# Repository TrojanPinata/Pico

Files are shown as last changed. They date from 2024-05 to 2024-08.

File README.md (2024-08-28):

# Pico
This project is a precursor to a future project which I aim to use a RP2040 as the microcontroller as the core of a keyboard, very similar to my original keyboard but with PCBA.

The goal of this was to prove the feasability of using PCBA as well as prove my ability to make a functioning RP2040 microcontroller board. The Pi Pico was simply chosen as it was a very accessible option.

If you want to use this project, it should be noted that this is open source, but I would rather you simply use this as a reference. Putting that much confidence in someone elses work is dangerous, and I cannot guarantee spec with the original.

The only major changes with these boards vs the real deal are the addition of a reset button and usb-c header (something that should be on the original :| )



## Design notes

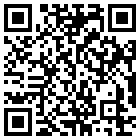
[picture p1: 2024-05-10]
assets/qr1.gif

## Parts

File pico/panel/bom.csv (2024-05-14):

Designator | Footprint | Quantity | Value | LCSC Part #
C1_6, C1_5, C1_4, C1_3, C1_2, C1, C10_6, C10_5, C10_4, C10_3, C10_2, C10, C16_6, C16_5, C16_4, C16_3, C16_2, C16, C17_6, C17_5, C17_4, C17_3, C17_2, C17, C2_6, C2_5, C2_4, C2_3, C2_2, C2, C4_6, C4_5, C4_4, C4_3, C4_2, C4, C5_6, C5_5, C5_4, C5_3, C5_2, C5, C6_6, C6_5, C6_4, C6_3, C6_2, C6, C7_6, C7_5, C7_4, C7_3, C7_2, C7, C8_6, C8_5, C8_4, C8_3, C8_2, C8, C9_6, C9_5, C9_4, C9_3, C9_2, C9 | 0402 | 66 | 0.1uF | C1525
C11_6, C11_5, C11_4, C11_3, C11_2, C11, C12_6, C12_5, C12_4, C12_3, C12_2, C12 | 0402 | 12 | 2.2uF | C12530
C13_6, C13_5, C13_4, C13_3, C13_2, C13, C19_6, C19_5, C19_4, C19_3, C19_2, C19 | 0402 | 12 | 10uF | C15525
C14_6, C14_5, C14_4, C14_3, C14_2, C14, C15_6, C15_5, C15_4, C15_3, C15_2, C15 | 0402 | 12 | 20pF | C1554
C3_6, C3_5, C3_4, C3_3, C3_2, C3 | 0402 | 6 | 1uF | C52923
D1_6, D1_5, D1_4, D1_3, D1_2, D1 | 0402 | 6 | LED | C2856703
D3_6, D3_5, D3_4, D3_3, D3_2, D3 | D_SOD-123 | 6 | 1N4002W | C169542
F1_6, F1_5, F1_4, F1_3, F1_2, F1 | 0805 | 6 | 0805L050WR | C207022
FB1_6, FB1_5, FB1_4, FB1_3, FB1_2, FB1 | 0402 | 6 | FB | C160973
J4_6, J4_5, J4_4, J4_3, J4_2, J4 | HRO-TYPE-C-31-M-12 | 6 | USB_C_Receptacle_USB2.0 | C165948
R1_6, R1_5, R1_4, R1_3, R1_2, R1, R2_6, R2_5, R2_4, R2_3, R2_2, R2 | 0402 | 12 | 27 | C25100
R10_6, R10_5, R10_4, R10_3, R10_2, R10, R14_6, R14_5, R14_4, R14_3, R14_2, R14, R9_6, R9_5, R9_4, R9_3, R9_2, R9 | 0402 | 18 | 10k | C25744
R11_6, R11_5, R11_4, R11_3, R11_2, R11, R12_6, R12_5, R12_4, R12_3, R12_2, R12 | 0402 | 12 | 5.1k | C25905
R13_6, R13_5, R13_4, R13_3, R13_2, R13 | 0402 | 6 | 5.6k | C25908
R15_6, R15_5, R15_4, R15_3, R15_2, R15 | 0402 | 6 | 100k | C25741
R3_6, R3_5, R3_4, R3_3, R3_2, R3 | 0402 | 6 | 200 | C25087
R4_6, R4_5, R4_4, R4_3, R4_2, R4 | 0402 | 6 | 1 | C25086
R5_6, R5_5, R5_4, R5_3, R5_2, R5 | 0402 | 6 | 470 | C25117
R7_6, R7_5, R7_4, R7_3, R7_2, R7, R8_6, R8_5, R8_4, R8_3, R8_2, R8 | 0402 | 12 | 1k | C11702
SW1_6, SW1_5, SW1_4, SW1_3, SW1_2, SW1 | SW_Push_SPST_NO_Alps_SKRK | 6 | RESET | C139797
SW2_6, SW2_5, SW2_4, SW2_3, SW2_2, SW2 | SW_Push_SPST_NO_Alps_SKRK | 6 | BOOT_SEL | C139797
U1_6, U1_5, U1_4, U1_3, U1_2, U1 | RP2040-QFN-56 | 6 | RP2040 | C2040
U2_6, U2_5, U2_4, U2_3, U2_2, U2 | SON-8-1EP_3x2mm_P0.5mm_EP1.4x1.6mm | 6 | W25Q16JVUXIQ | C2843335
U3_6, U3_5, U3_4, U3_3, U3_2, U3 | SOT-23-5 | 6 | TLV75533PDBVR | C404027
Y1_6, Y1_5, Y1_4, Y1_3, Y1_2, Y1 | Crystal_SMD_3225-4Pin_3.2x2.5mm | 6 | 12MHz | C9002

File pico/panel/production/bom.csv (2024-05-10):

Designator | Footprint | Quantity | Value | LCSC Part #
C1_6, C1_5, C1_4, C1_3, C1_2, C1, C10_6, C10_5, C10_4, C10_3, C10_2, C10, C16_6, C16_5, C16_4, C16_3, C16_2, C16, C17_6, C17_5, C17_4, C17_3, C17_2, C17, C2_6, C2_5, C2_4, C2_3, C2_2, C2, C4_6, C4_5, C4_4, C4_3, C4_2, C4, C5_6, C5_5, C5_4, C5_3, C5_2, C5, C6_6, C6_5, C6_4, C6_3, C6_2, C6, C7_6, C7_5, C7_4, C7_3, C7_2, C7, C8_6, C8_5, C8_4, C8_3, C8_2, C8, C9_6, C9_5, C9_4, C9_3, C9_2, C9 | 0402 | 66 | 0.1uF
C11_6, C11_5, C11_4, C11_3, C11_2, C11, C12_6, C12_5, C12_4, C12_3, C12_2, C12 | 0402 | 12 | 2.2uF
C13_6, C13_5, C13_4, C13_3, C13_2, C13, C19_6, C19_5, C19_4, C19_3, C19_2, C19 | 0402 | 12 | 10uF
C14_6, C14_5, C14_4, C14_3, C14_2, C14, C15_6, C15_5, C15_4, C15_3, C15_2, C15 | 0402 | 12 | 22pF
C3_6, C3_5, C3_4, C3_3, C3_2, C3 | 0402 | 6 | 1uF
D1_6, D1_5, D1_4, D1_3, D1_2, D1 | 0402 | 6 | LED
D3_6, D3_5, D3_4, D3_3, D3_2, D3 | D_SOD-123 | 6 | 1N4002W
F1_6, F1_5, F1_4, F1_3, F1_2, F1 | 0805 | 6 | 0805L050WR
FB1_6, FB1_5, FB1_4, FB1_3, FB1_2, FB1 | 0402 | 6 | FB
J1_6, J1_5, J1_4, J1_3, J1_2, J1 | PinHeader_1x20_P2.54mm_Vertical | 6 | LEFT_PINS
J2_6, J2_5, J2_4, J2_3, J2_2, J2 | PinHeader_1x20_P2.54mm_Vertical | 6 | RIGHT_PINS
J3_6, J3_5, J3_4, J3_3, J3_2, J3 | PinHeader_1x03_P2.54mm_Vertical | 6 | BOTTOM_PINS
J4_6, J4_5, J4_4, J4_3, J4_2, J4 | HRO-TYPE-C-31-M-12 | 6 | USB_C_Receptacle_USB2.0
KiKit_MB_10_1, KiKit_MB_10_2, KiKit_MB_10_3, KiKit_MB_10_4, KiKit_MB_10_5, KiKit_MB_10_6, KiKit_MB_10_7, KiKit_MB_10_8, KiKit_MB_11_1, KiKit_MB_11_2, KiKit_MB_11_3, KiKit_MB_11_4, KiKit_MB_11_5, KiKit_MB_11_6, KiKit_MB_11_7, KiKit_MB_11_8, KiKit_MB_12_1, KiKit_MB_12_2, KiKit_MB_12_3, KiKit_MB_12_4, KiKit_MB_12_5, KiKit_MB_12_6, KiKit_MB_12_7, KiKit_MB_12_8, KiKit_MB_13_1, KiKit_MB_13_2, KiKit_MB_13_3, KiKit_MB_13_4, KiKit_MB_13_5, KiKit_MB_13_6, KiKit_MB_13_7, KiKit_MB_13_8, KiKit_MB_14_1, KiKit_MB_14_2, KiKit_MB_14_3, KiKit_MB_14_4, KiKit_MB_14_5, KiKit_MB_14_6, KiKit_MB_14_7, KiKit_MB_14_8, KiKit_MB_15_1, KiKit_MB_15_2, KiKit_MB_15_3, KiKit_MB_15_4, KiKit_MB_15_5, KiKit_MB_15_6, KiKit_MB_15_7, KiKit_MB_15_8, KiKit_MB_16_1, KiKit_MB_16_2, KiKit_MB_16_3, KiKit_MB_16_4, KiKit_MB_16_5, KiKit_MB_16_6, KiKit_MB_16_7, KiKit_MB_16_8, KiKit_MB_17_1, KiKit_MB_17_2, KiKit_MB_17_3, KiKit_MB_17_4, KiKit_MB_17_5, KiKit_MB_17_6, KiKit_MB_17_7, KiKit_MB_17_8, KiKit_MB_18_1, KiKit_MB_18_2, KiKit_MB_18_3, KiKit_MB_18_4, KiKit_MB_18_5, KiKit_MB_18_6, KiKit_MB_18_7, KiKit_MB_18_8, KiKit_MB_19_1, KiKit_MB_19_2, KiKit_MB_19_3, KiKit_MB_19_4, KiKit_MB_19_5, KiKit_MB_19_6, KiKit_MB_19_7, KiKit_MB_19_8, KiKit_MB_1_1, KiKit_MB_1_2, KiKit_MB_1_3, KiKit_MB_1_4, KiKit_MB_1_5, KiKit_MB_1_6, KiKit_MB_1_7, KiKit_MB_1_8, KiKit_MB_20_1, KiKit_MB_20_2, KiKit_MB_20_3, KiKit_MB_20_4, KiKit_MB_20_5, KiKit_MB_20_6, KiKit_MB_20_7, KiKit_MB_20_8, KiKit_MB_21_1, KiKit_MB_21_2, KiKit_MB_21_3, KiKit_MB_21_4, KiKit_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 | NPTH | 200 | NPTH
KiKit_MB_33_1, KiKit_MB_33_2, KiKit_MB_33_3, KiKit_MB_33_4, KiKit_MB_33_5, KiKit_MB_33_6, KiKit_MB_33_7, KiKit_MB_33_8, KiKit_MB_34_1, KiKit_MB_34_2, KiKit_MB_34_3, KiKit_MB_34_4, KiKit_MB_34_5, KiKit_MB_34_6, KiKit_MB_34_7, KiKit_MB_34_8, KiKit_MB_35_1, KiKit_MB_35_2, KiKit_MB_35_3, KiKit_MB_35_4, KiKit_MB_35_5, KiKit_MB_35_6, KiKit_MB_35_7, KiKit_MB_35_8, KiKit_MB_36_1, KiKit_MB_36_2, KiKit_MB_36_3, KiKit_MB_36_4, KiKit_MB_36_5, KiKit_MB_36_6, KiKit_MB_36_7, KiKit_MB_36_8, KiKit_MB_37_1, KiKit_MB_37_2, KiKit_MB_37_3, KiKit_MB_37_4, KiKit_MB_37_5, KiKit_MB_37_6, KiKit_MB_37_7, KiKit_MB_37_8, KiKit_MB_38_1, KiKit_MB_38_2, KiKit_MB_38_3, KiKit_MB_38_4, KiKit_MB_38_5, KiKit_MB_38_6, KiKit_MB_38_7, KiKit_MB_38_8, KiKit_MB_39_1, KiKit_MB_39_2, KiKit_MB_39_3, KiKit_MB_39_4, KiKit_MB_39_5, KiKit_MB_39_6, KiKit_MB_39_7, KiKit_MB_39_8, KiKit_MB_3_1, KiKit_MB_3_2, KiKit_MB_3_3, KiKit_MB_3_4, KiKit_MB_3_5, KiKit_MB_3_6, KiKit_MB_3_7, KiKit_MB_3_8, KiKit_MB_40_1, KiKit_MB_40_2, KiKit_MB_40_3, KiKit_MB_40_4, KiKit_MB_40_5, KiKit_MB_40_6, KiKit_MB_40_7, KiKit_MB_40_8, KiKit_MB_41_1, KiKit_MB_41_2, KiKit_MB_41_3, KiKit_MB_41_4, KiKit_MB_41_5, KiKit_MB_41_6, KiKit_MB_41_7, KiKit_MB_41_8, KiKit_MB_42_1, KiKit_MB_42_2, KiKit_MB_42_3, KiKit_MB_42_4, KiKit_MB_42_5, KiKit_MB_42_6, KiKit_MB_42_7, KiKit_MB_42_8, KiKit_MB_43_1, KiKit_MB_43_2, KiKit_MB_43_3, KiKit_MB_43_4, KiKit_MB_43_5, KiKit_MB_43_6, KiKit_MB_43_7, KiKit_MB_43_8, KiKit_MB_44_1, KiKit_MB_44_2, KiKit_MB_44_3, KiKit_MB_44_4, KiKit_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 | NPTH | 200 | NPTH
KiKit_MB_57_5, KiKit_MB_57_6, KiKit_MB_57_7, KiKit_MB_58_1, KiKit_MB_58_2, KiKit_MB_58_3, KiKit_MB_58_4, KiKit_MB_58_5, KiKit_MB_58_6, KiKit_MB_58_7, KiKit_MB_59_1, KiKit_MB_59_2, KiKit_MB_59_3, KiKit_MB_59_4, KiKit_MB_59_5, KiKit_MB_59_6, KiKit_MB_59_7, KiKit_MB_5_1, KiKit_MB_5_2, KiKit_MB_5_3, KiKit_MB_5_4, KiKit_MB_5_5, KiKit_MB_5_6, KiKit_MB_5_7, KiKit_MB_5_8, KiKit_MB_60_1, KiKit_MB_60_2, KiKit_MB_60_3, KiKit_MB_60_4, KiKit_MB_60_5, KiKit_MB_60_6, KiKit_MB_60_7, KiKit_MB_6_1, KiKit_MB_6_2, KiKit_MB_6_3, KiKit_MB_6_4, KiKit_MB_6_5, KiKit_MB_6_6, KiKit_MB_6_7, KiKit_MB_6_8, KiKit_MB_7_1, KiKit_MB_7_2, KiKit_MB_7_3, KiKit_MB_7_4, KiKit_MB_7_5, KiKit_MB_7_6, KiKit_MB_7_7, KiKit_MB_7_8, KiKit_MB_8_1, KiKit_MB_8_2, KiKit_MB_8_3, KiKit_MB_8_4, KiKit_MB_8_5, KiKit_MB_8_6, KiKit_MB_8_7, KiKit_MB_8_8, KiKit_MB_9_1, KiKit_MB_9_2, KiKit_MB_9_3, KiKit_MB_9_4, KiKit_MB_9_5, KiKit_MB_9_6, KiKit_MB_9_7, KiKit_MB_9_8 | NPTH | 64 | NPTH
R1_6, R1_5, R1_4, R1_3, R1_2, R1, R2_6, R2_5, R2_4, R2_3, R2_2, R2 | 0402 | 12 | 27
R10_6, R10_5, R10_4, R10_3, R10_2, R10, R14_6, R14_5, R14_4, R14_3, R14_2, R14, R9_6, R9_5, R9_4, R9_3, R9_2, R9 | 0402 | 18 | 10k
R11_6, R11_5, R11_4, R11_3, R11_2, R11, R12_6, R12_5, R12_4, R12_3, R12_2, R12 | 0402 | 12 | 5.1k
R13_6, R13_5, R13_4, R13_3, R13_2, R13 | 0402 | 6 | 5.6k
R15_6, R15_5, R15_4, R15_3, R15_2, R15 | 0402 | 6 | 100k
R3_6, R3_5, R3_4, R3_3, R3_2, R3 | 0402 | 6 | 200
R4_6, R4_5, R4_4, R4_3, R4_2, R4 | 0402 | 6 | 1
R5_6, R5_5, R5_4, R5_3, R5_2, R5 | 0402 | 6 | 470
R7_6, R7_5, R7_4, R7_3, R7_2, R7, R8_6, R8_5, R8_4, R8_3, R8_2, R8 | 0402 | 12 | 1k
SW1_6, SW1_5, SW1_4, SW1_3, SW1_2, SW1 | SW_Push_SPST_NO_Alps_SKRK | 6 | RESET
SW2_6, SW2_5, SW2_4, SW2_3, SW2_2, SW2 | SW_Push_SPST_NO_Alps_SKRK | 6 | BOOT_SEL
TP1_6, TP1_5, TP1_4, TP1_3, TP1_2, TP1, TP2_6, TP2_5, TP2_4, TP2_3, TP2_2, TP2, TP3_6, TP3_5, TP3_4, TP3_3, TP3_2, TP3 | CustomTestPoint | 18 | TestPoint
U1_6, U1_5, U1_4, U1_3, U1_2, U1 | RP2040-QFN-56 | 6 | RP2040
U2_6, U2_5, U2_4, U2_3, U2_2, U2 | SON-8-1EP_3x2mm_P0.5mm_EP1.4x1.6mm | 6 | W25Q16JVUXIQ
U3_6, U3_5, U3_4, U3_3, U3_2, U3 | SOT-23-5 | 6 | TLV75533PDBVR
Y1_6, Y1_5, Y1_4, Y1_3, Y1_2, Y1 | Crystal_SMD_3225-4Pin_3.2x2.5mm | 6 | 12MHz

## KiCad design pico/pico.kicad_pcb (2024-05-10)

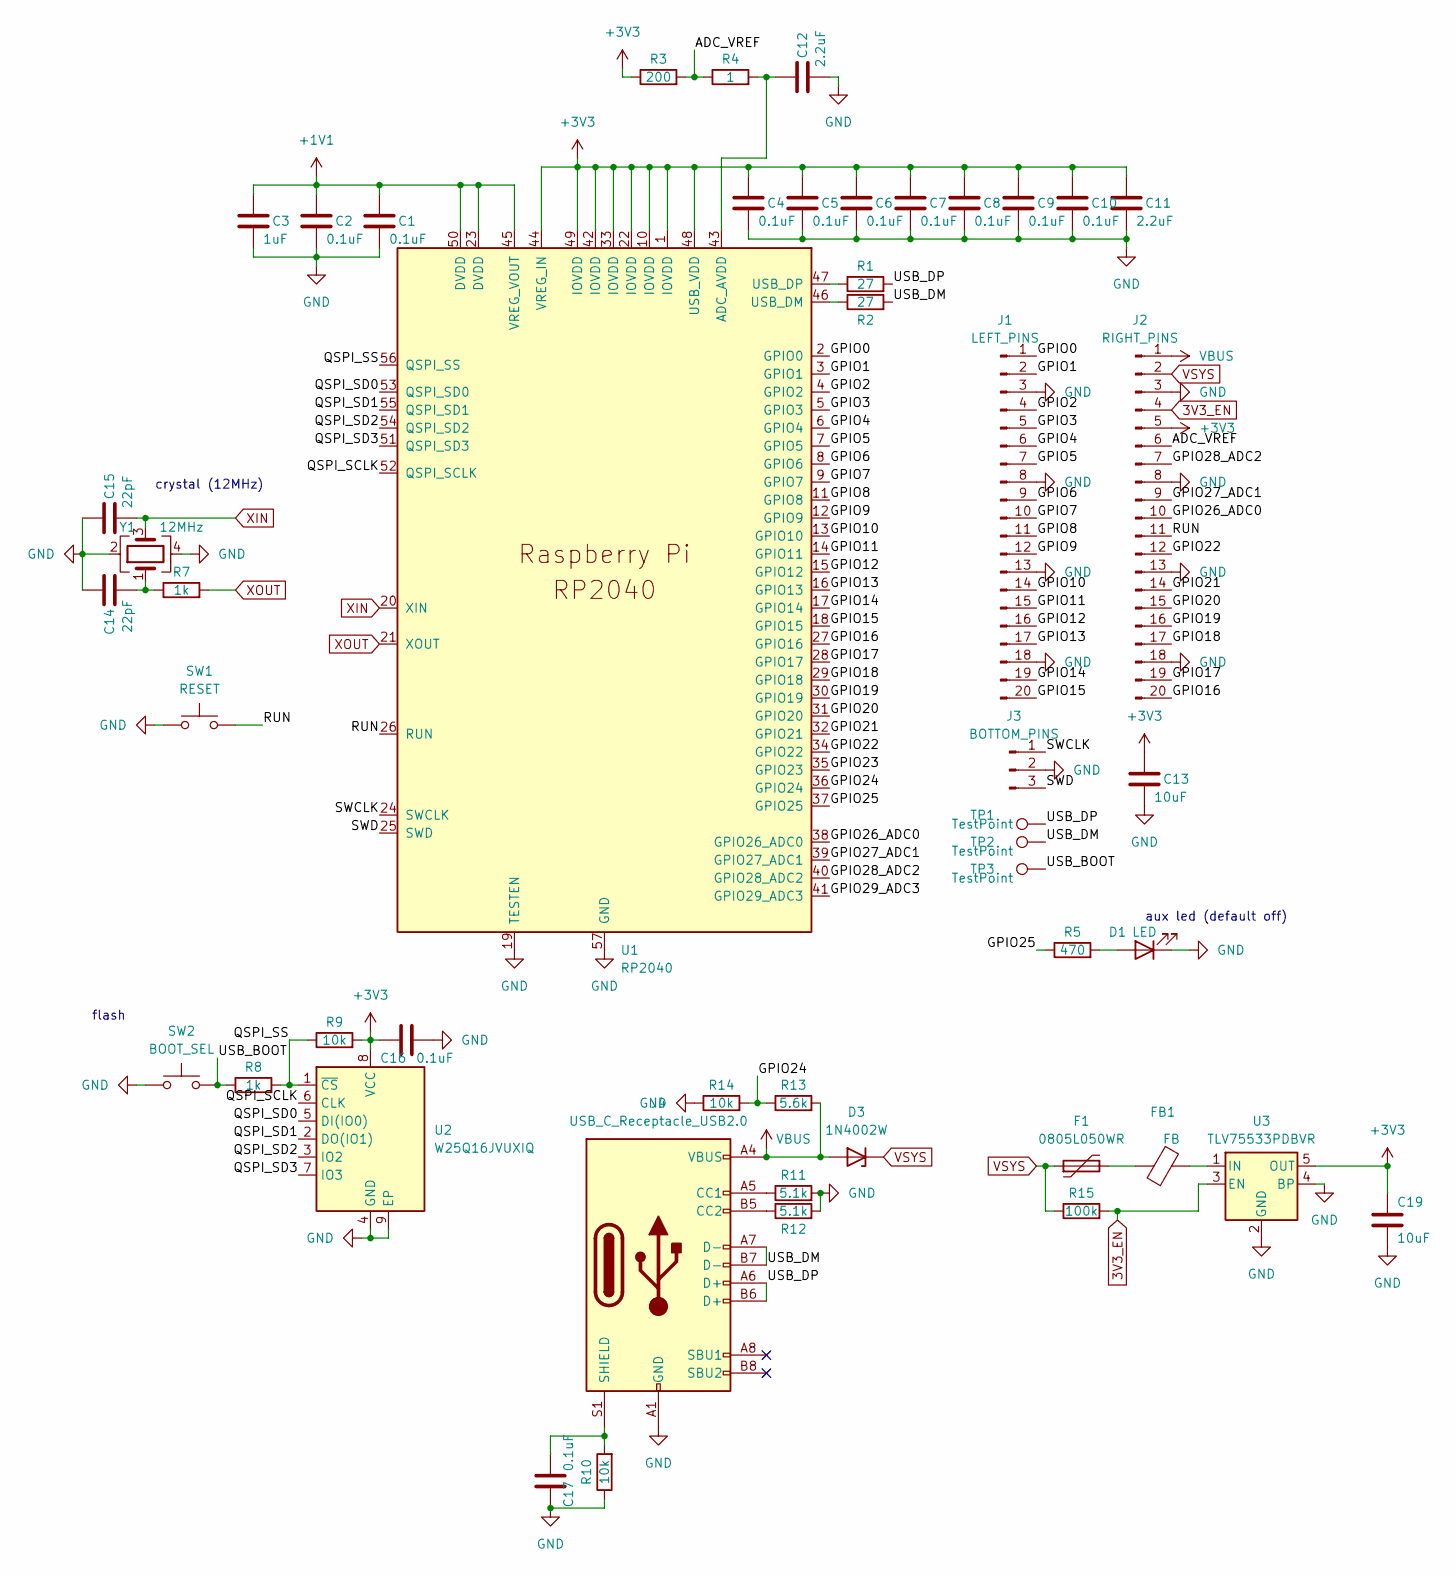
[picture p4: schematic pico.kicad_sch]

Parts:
C1, C2, C4, C5, C6, C7, C8, C9, C10, C16, C17: 0.1uF; C_0402_1005Metric
C3: 1uF; C_0402_1005Metric
C11, C12: 2.2uF; C_0402_1005Metric
C13, C19: 10uF; C_0402_1005Metric
C14, C15: 22pF; C_0402_1005Metric
D1: LED; LED_0402_1005Metric
D3: 1N4002W; D_SOD-123
F1: 0805L050WR; Fuse_0805_2012Metric
FB1: FB; R_0402_1005Metric
J1: LEFT_PINS; PinHeader_1x20_P2.54mm_Vertical
J2: RIGHT_PINS; PinHeader_1x20_P2.54mm_Vertical
J3: BOTTOM_PINS; PinHeader_1x03_P2.54mm_Vertical
J4: USB_C_Receptacle_USB2.0; HRO-TYPE-C-31-M-12
R1, R2: 27; R_0402_1005Metric
R3: 200; R_0402_1005Metric
R4: 1; R_0402_1005Metric
R5: 470; R_0402_1005Metric
R7, R8: 1k; R_0402_1005Metric
R9, R10, R14: 10k; R_0402_1005Metric
R11, R12: 5.1k; R_0402_1005Metric
R13: 5.6k; R_0402_1005Metric
R15: 100k; R_0402_1005Metric
SW1: RESET; SW_Push_SPST_NO_Alps_SKRK
SW2: BOOT_SEL; SW_Push_SPST_NO_Alps_SKRK
TP1, TP2, TP3: TestPoint; CustomTestPoint
U1: RP2040; RP2040-QFN-56
U2: W25Q16JVUXIQ; SON-8-1EP_3x2mm_P0.5mm_EP1.4x1.6mm
U3: TLV75533PDBVR; SOT-23-5
Y1: 12MHz; Crystal_SMD_3225-4Pin_3.2x2.5mm

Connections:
3V3_EN: J2.4, R15.2, U3.3 (EN)
+1V1: C1.1, C2.1, C3.1, U1.23 (DVDD), U1.45 (VREG_VOUT), U1.50 (DVDD)
+3V3: C4.1, C5.1, C6.1, C7.1, C8.1, C9.1, C10.1, C11.1, C13.1, C16.2, C19.1, J2.5, R3.1, R9.2, U1.1 (IOVDD), U1.10 (IOVDD), U1.22 (IOVDD), U1.33 (IOVDD), U1.42 (IOVDD), U1.44 (VREG_IN), U1.48 (USB_VDD), U1.49 (IOVDD), U2.8 (VCC), U3.5 (OUT)
/ADC_VREF: J2.6, R3.2, R4.1
/GPIO0: J1.1, U1.2 (GPIO0)
/GPIO1: J1.2, U1.3 (GPIO1)
/GPIO2: J1.4, U1.4 (GPIO2)
/GPIO3: J1.5, U1.5 (GPIO3)
/GPIO4: J1.6, U1.6 (GPIO4)
/GPIO5: J1.7, U1.7 (GPIO5)
/GPIO6: J1.9, U1.8 (GPIO6)
/GPIO7: J1.10, U1.9 (GPIO7)
/GPIO8: J1.11, U1.11 (GPIO8)
/GPIO9: J1.12, U1.12 (GPIO9)
/GPIO10: J1.14, U1.13 (GPIO10)
/GPIO11: J1.15, U1.14 (GPIO11)
/GPIO12: J1.16, U1.15 (GPIO12)
/GPIO13: J1.17, U1.16 (GPIO13)
/GPIO14: J1.19, U1.17 (GPIO14)
/GPIO15: J1.20, U1.18 (GPIO15)
/GPIO16: J2.20, U1.27 (GPIO16)
/GPIO17: J2.19, U1.28 (GPIO17)
/GPIO18: J2.17, U1.29 (GPIO18)
/GPIO19: J2.16, U1.30 (GPIO19)
/GPIO20: J2.15, U1.31 (GPIO20)
/GPIO21: J2.14, U1.32 (GPIO21)
/GPIO22: J2.12, U1.34 (GPIO22)
/GPIO23: U1.35 (GPIO23)
/GPIO24: R13.1, R14.2, U1.36 (GPIO24)
/GPIO25: R5.1, U1.37 (GPIO25)
/GPIO26_ADC0: J2.10, U1.38 (GPIO26_ADC0)
/GPIO27_ADC1: J2.9, U1.39 (GPIO27_ADC1)
/GPIO28_ADC2: J2.7, U1.40 (GPIO28_ADC2)
/GPIO29_ADC3: U1.41 (GPIO29_ADC3)
/QSPI_SCLK: U1.52 (QSPI_SCLK), U2.6 (CLK)
/QSPI_SD0: U1.53 (QSPI_SD0), U2.5 (DI(IO0))
/QSPI_SD1: U1.55 (QSPI_SD1), U2.2 (DO(IO1))
/QSPI_SD2: U1.54 (QSPI_SD2), U2.3 (IO2)
/QSPI_SD3: U1.51 (QSPI_SD3), U2.7 (IO3)
/QSPI_SS: R8.2, R9.1, U1.56 (QSPI_SS), U2.1 (~CS)
/RUN: J2.11, SW1.2, U1.26 (RUN)
/SWCLK: J3.1, U1.24 (SWCLK)
/SWD: J3.3, U1.25 (SWD)
/USB_BOOT: R8.1, SW2.2, TP3.1
/USB_DM: J4.A7 (D-), J4.B7 (D-), R2.2, TP2.1
/USB_DP: J4.A6 (D+), J4.B6 (D+), R1.2, TP1.1
GND: C1.2, C2.2, C3.2, C4.2, C5.2, C6.2, C7.2, C8.2, C9.2, C10.2, C11.2, C12.2, C13.2, C14.2, C15.1, C16.1, C17.2, C19.2, D1.1 (K), J1.3, J1.8, J1.13, J1.18, J2.3, J2.8, J2.13, J2.18, J3.2, J4.A1 (GND), J4.A12 (GND), J4.B1 (GND), J4.B12 (GND), R10.1, R11.2, R12.2, R14.1, SW1.1, SW2.1, U1.19 (TESTEN), U1.57 (GND), U2.4 (GND), U2.9 (EP), U3.2 (GND), U3.4 (BP), Y1.2, Y1.4
unnamed: C14.1, R7.1, Y1.1
unnamed: D1.2 (A), R5.2
unnamed: F1.2, FB1.2
unnamed: J4.A5 (CC1), R11.1
unnamed: J4.B5 (CC2), R12.1
unnamed: C17.1, J4.S1 (SHIELD), R10.2
unnamed: C12.1, R4.2, U1.43 (ADC_AVDD)
unnamed: R2.1, U1.46 (USB_DM)
unnamed: R1.1, U1.47 (USB_DP)
unnamed: FB1.1, U3.1 (IN)
VBUS: D3.2 (A), J2.1, J4.A4 (VBUS), J4.A9 (VBUS), J4.B4 (VBUS), J4.B9 (VBUS), R13.2
VSYS: D3.1 (K), F1.1, J2.2, R15.1
XIN: C15.2, U1.20 (XIN), Y1.3
XOUT: R7.2, U1.21 (XOUT)

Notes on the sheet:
aux led (default off)
crystal (12MHz)
flash

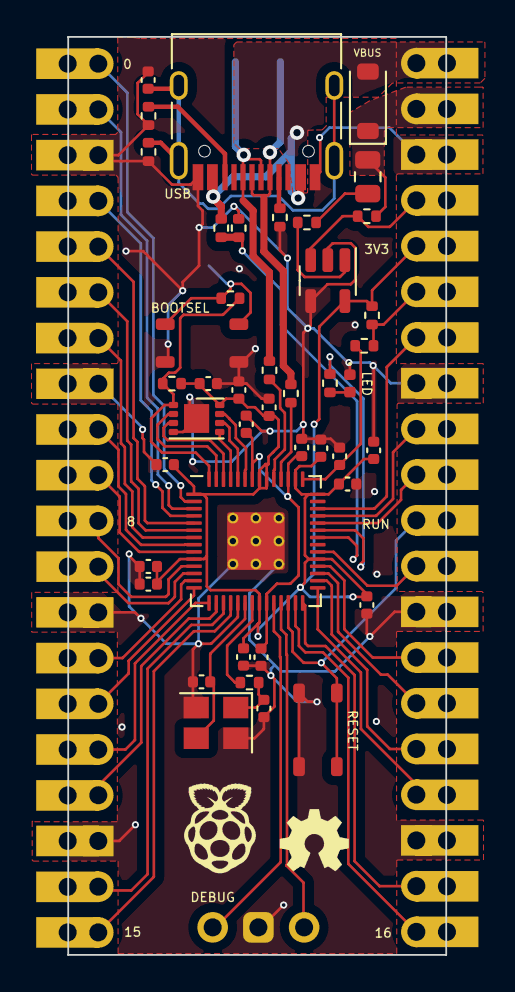
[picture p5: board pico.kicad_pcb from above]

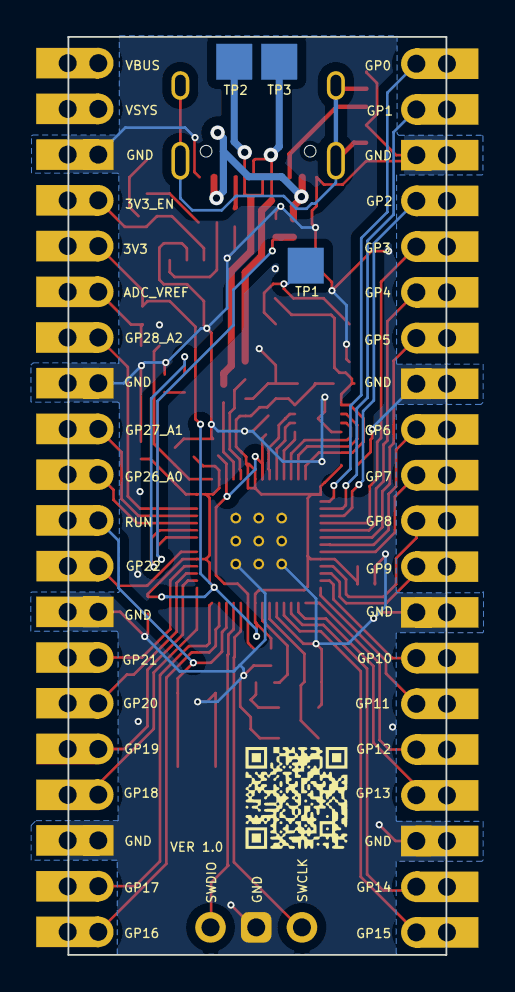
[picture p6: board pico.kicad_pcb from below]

Board: 2 copper layers, 21.0 x 51.0 mm, 49 parts (3 on the bottom side), 59 nets.

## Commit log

2024-05-10 v1.0 w/ panels
    [bom.csv, designators.csv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]
2024-05-14 bom modifications
    [bom.csv, positions.csv]
2024-05-17 add license
    I have to add licenses to all of my repos bc people are stealing some of them and selling them (╥﹏╥)
